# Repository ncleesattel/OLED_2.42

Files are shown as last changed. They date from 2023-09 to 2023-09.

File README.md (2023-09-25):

## OLED 242 pcb
This is an alternative pcb to the one provided by DIYmore.
A key difference is that no smd soldering is necessary to switch from SPI mode to I2C mode.
Instead there is a switch pad that can be used.

I use this pcb to connect 2.42 inch displays from Aliexpress to either my SHC build or the ESP32 dew heater.
Look for 2.42" 128x64 SSD1309 displays and the assoc. metal frame.

## ordering
The pcb is designed in KiCad.  
In the jlcpcb folder you can find the Gerber, BOM and CPL file you need to not only order the pcb, but also the assembled smd parts.

## cost estimate
| Item | Number | Cost |
|---|---|---|
| pcb | 5 | 60 |
| frame | 5 | 13 |
| display | 5 | 52 |

Best case you can use all displays equals to 25/unit.  
Worst case you just need one and can't share the cost of the other four equals to 125. 

## pictures

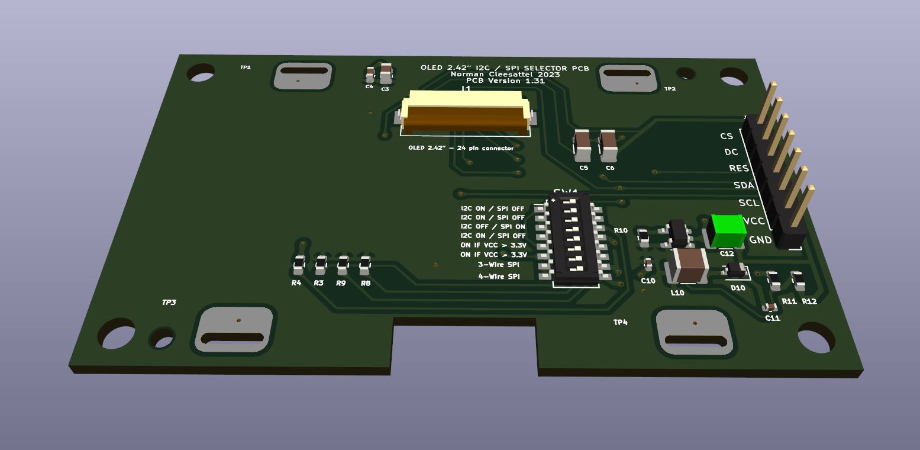
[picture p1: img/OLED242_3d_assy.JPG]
OLED 242 3d pcb


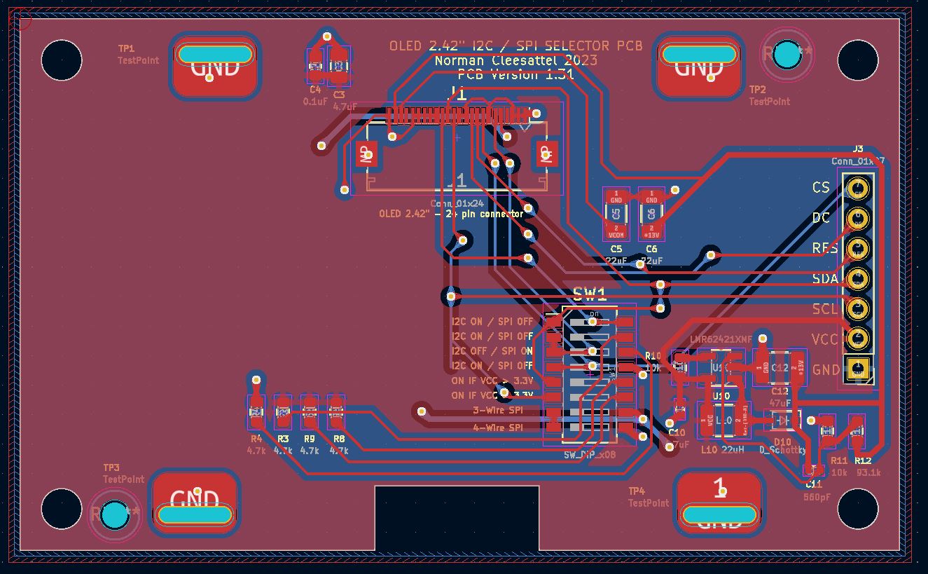
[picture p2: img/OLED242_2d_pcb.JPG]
OLED 242 2d pcb


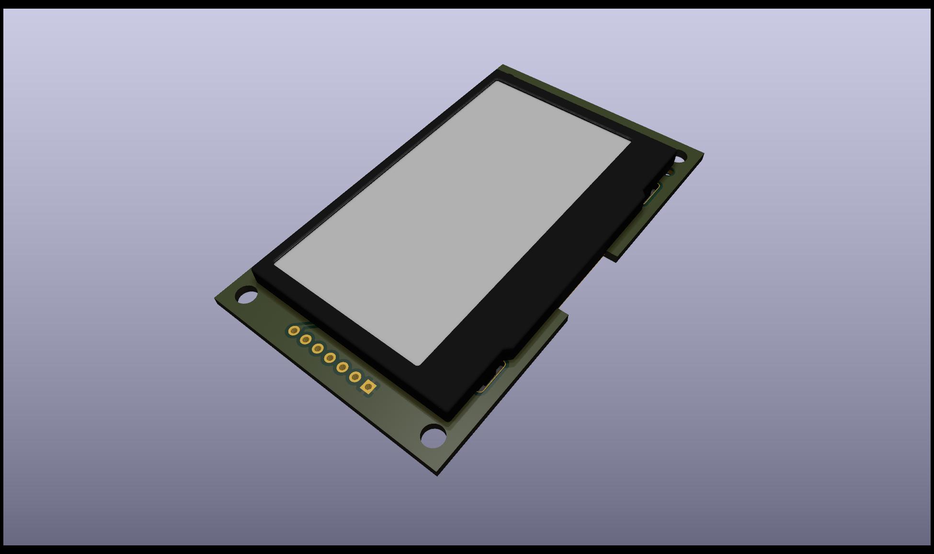
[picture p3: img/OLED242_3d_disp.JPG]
OLED 242 3d disp


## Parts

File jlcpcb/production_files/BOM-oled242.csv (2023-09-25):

Comment | Designator | Footprint | LCSC
22uF | C5,C6 | C_1206_3216Metric | C12891
0.1uF | C4 | C_0603_1608Metric | C14663
4.7uF | C3 | C_0805_2012Metric | C1779
D_Schottky | D10 | D_SOD-323 | C191023
Conn_01x24 | J1 | Hirose_FH12-24S-0.5SH_1x24-1MP_P0.50mm_Horizontal | C202112
LMR62421XMF | U10 | SOT-23-5 | C206031
22uH | L10 | C_1210_3225Metric | C223225
SW_DIP_x08 | SW1 | SW_DIP_SPSTx08_Slide_Omron_A6H-8101_W6.15mm_P1.27mm | C224998
4.7k | R3,R4,R8,R9 | R_0603_1608Metric | C23162
4.7uF | C10 | C_0402_1005Metric | C23733
10k | R10,R11 | R_0603_1608Metric | C25804
560pF | C11 | C_0402_1005Metric | C464953
93.1k | R12 | R_0603_1608Metric | C705799
47uF | C12 | C_1210_3225Metric | C77101
TestPoint | TP2 | OLED_slot
OLED_slot | TP4 | OLED_slot
Conn_01x07 | J3 | PinHeader_1x07_P2.54mm_Vertical
TestPoint | TP3 | OLED_slot
TestPoint | TP1 | OLED_slot

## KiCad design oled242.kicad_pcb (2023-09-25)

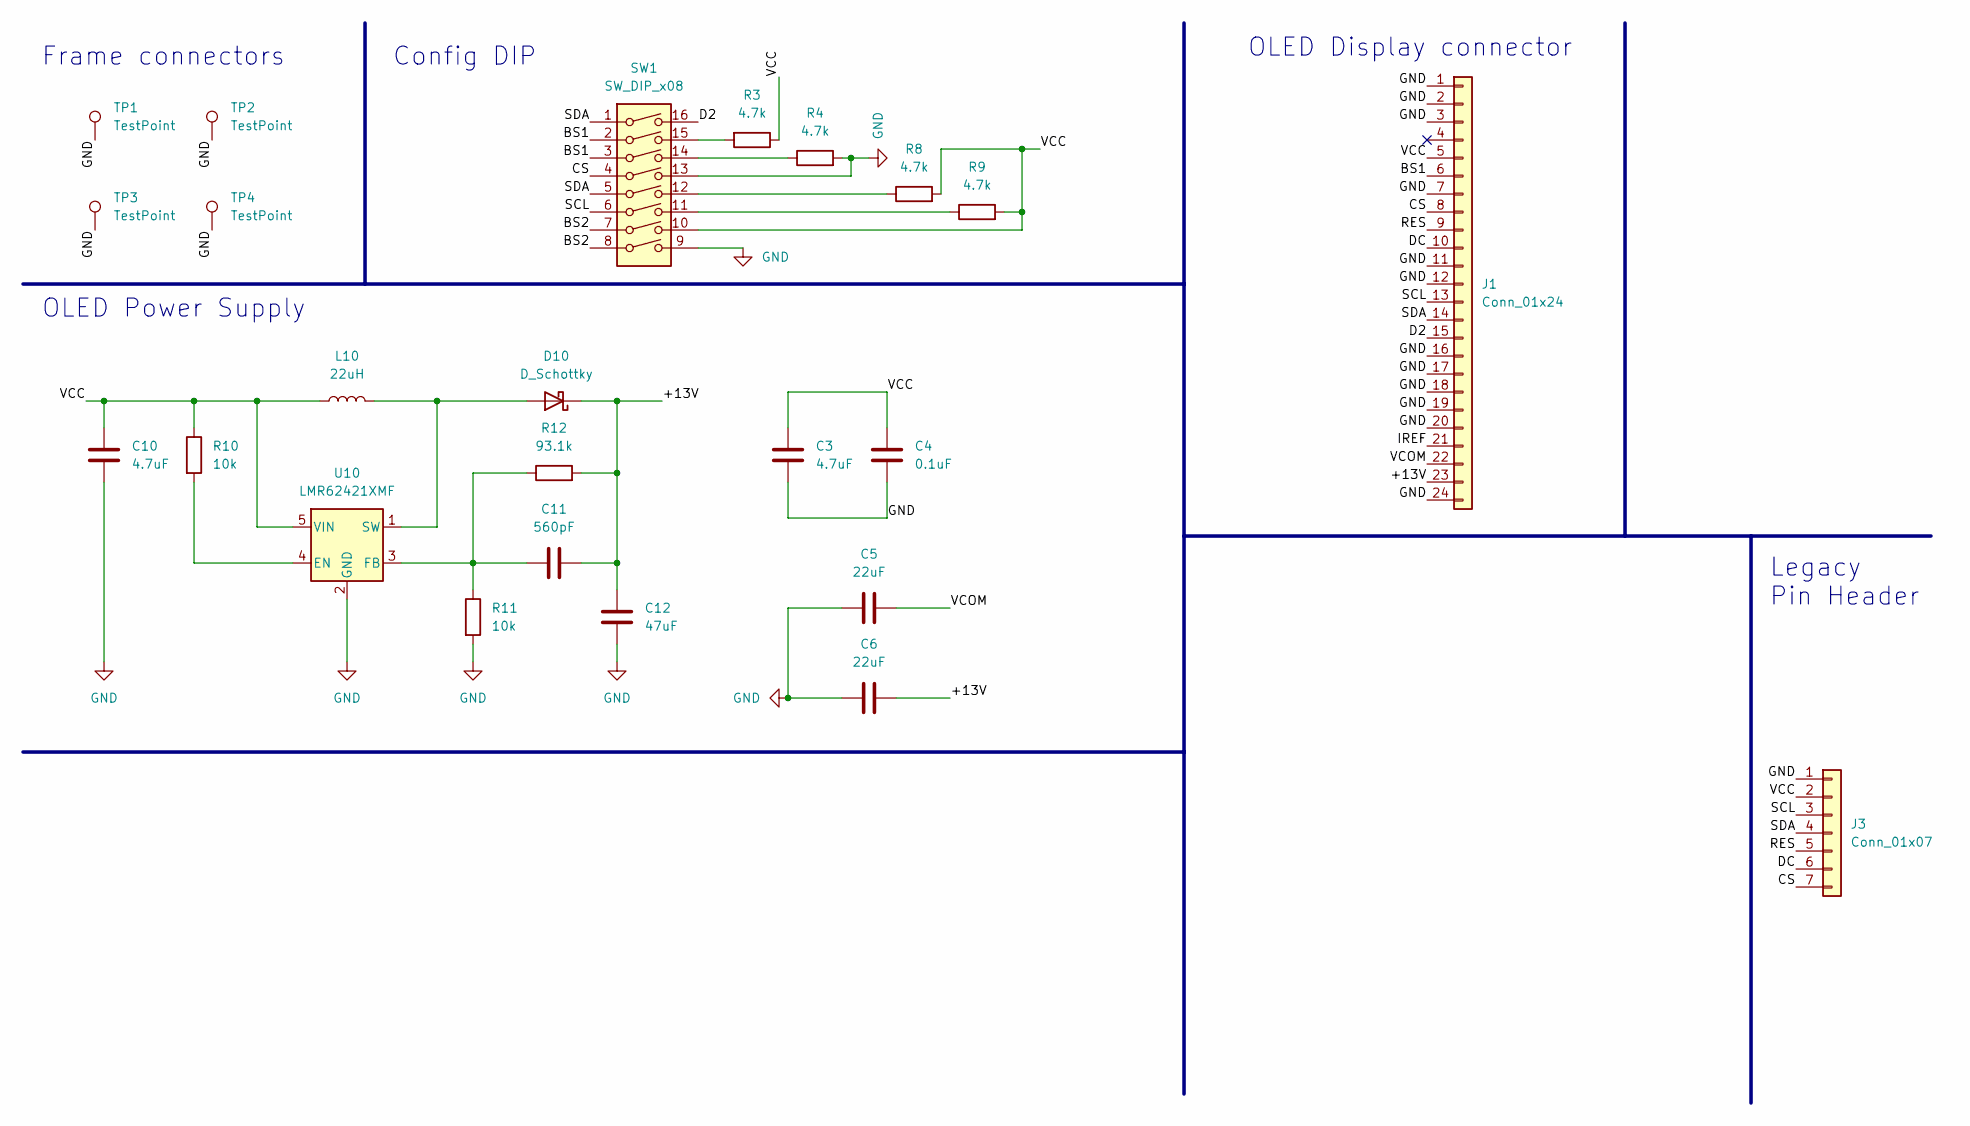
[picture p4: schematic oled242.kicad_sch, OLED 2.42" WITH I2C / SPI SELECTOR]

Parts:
C3: 4.7uF; C_0805_2012Metric; LCSC C1779
C4: 0.1uF; C_0603_1608Metric; LCSC C14663
C5, C6: 22uF; C_1206_3216Metric; LCSC C12891
C10: 4.7uF; C_0402_1005Metric; LCSC C23733
C11: 560pF; C_0402_1005Metric; LCSC C464953
C12: 47uF; C_1210_3225Metric; LCSC C77101
D10: D_Schottky; D_SOD-323; LCSC C191023
J1: Conn_01x24; Hirose_FH12-24S-0.5SH_1x24-1MP_P0.50mm_Horizontal; LCSC C506794
J3: Conn_01x07; PinHeader_1x07_P2.54mm_Vertical
L10: 22uH; C_1210_3225Metric; LCSC C223225
R3, R4, R8, R9: 4.7k; R_0603_1608Metric; LCSC C23162
R10, R11: 10k; R_0603_1608Metric; LCSC C25804
R12: 93.1k; R_0603_1608Metric; LCSC C705799
SW1: SW_DIP_x08; SW_DIP_SPSTx08_Slide_Omron_A6H-8101_W6.15mm_P1.27mm; LCSC C224998
TP1, TP2, TP3, TP4: TestPoint; OLED_slot
U10: LMR62421XMF; SOT-23-5; LCSC C206031

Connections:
/+13V: C6.2, C11.2, C12.2, D10.1 (K), J1.23, R12.2
/BS1: J1.6, SW1.2, SW1.3
/BS2: SW1.7, SW1.8
/CS: J1.8, J3.7, SW1.4
/D2: J1.15, SW1.16
/DC: J1.10, J3.6
/IREF: J1.21
/RES: J1.9, J3.5
/SCL: J1.13, J3.3, SW1.6
/SDA: J1.14, J3.4, SW1.1, SW1.5
/VCC: C3.1, C4.1, C10.1, J1.5, J3.2, L10.1, R3.1, R8.2, R9.2, R10.1, SW1.10, U10.5 (VIN)
/VCOM: C5.2, J1.22
GND: C3.2, C4.2, C5.1, C6.1, C10.2, C12.1, J1.1, J1.2, J1.3, J1.7, J1.11, J1.12, J1.16, J1.17, J1.18, J1.19, J1.20, J1.24, J3.1, R4.2, R11.2, SW1.9, SW1.13, TP1.1, TP2.1, TP3.1, TP4.1, U10.2 (GND)
unnamed: D10.2 (A), L10.2, U10.1 (SW)
unnamed: R3.2, SW1.15
unnamed: R4.1, SW1.14
unnamed: R8.1, SW1.12
unnamed: R9.1, SW1.11
unnamed: R10.2, U10.4 (EN)
unnamed: C11.1, R11.1, R12.1, U10.3 (FB)

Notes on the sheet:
Frame connectors
Legacy Pin Header
OLED Display connector
OLED Power Supply
Config DIP

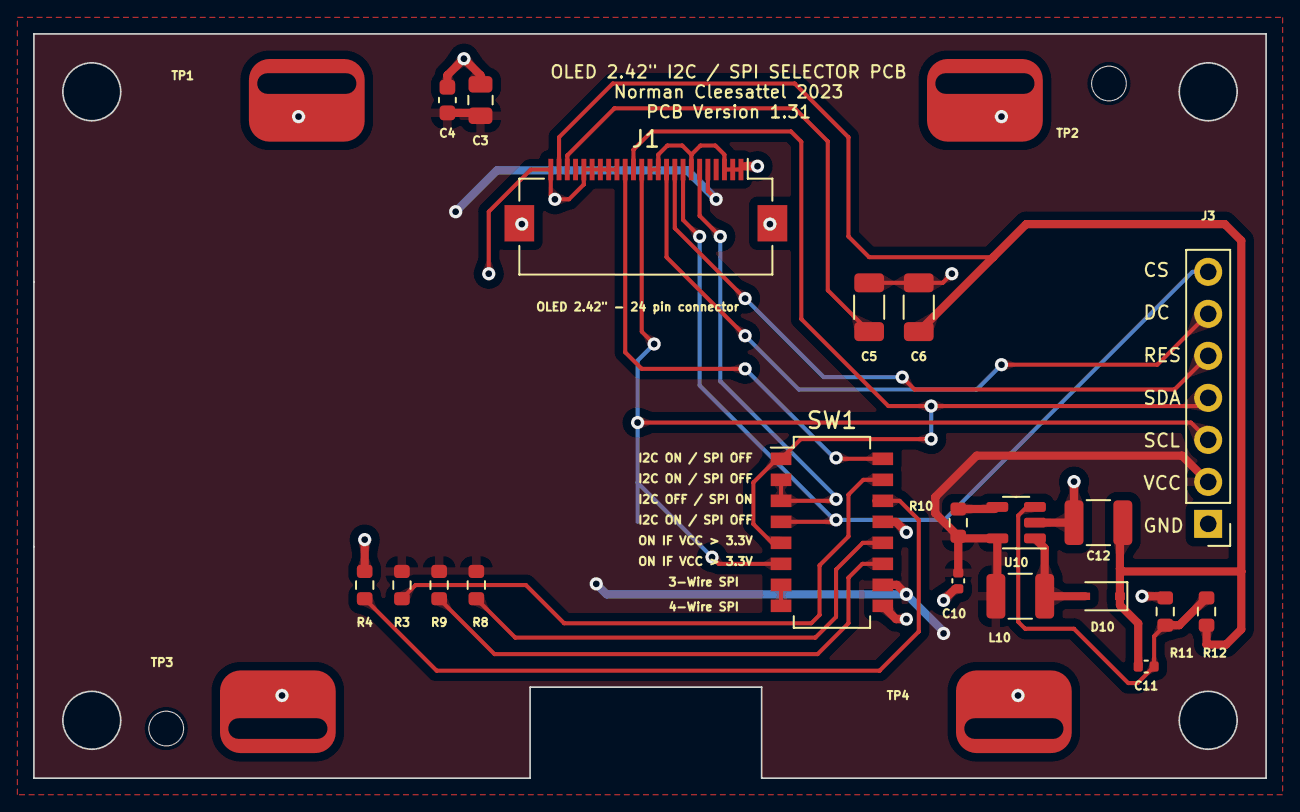
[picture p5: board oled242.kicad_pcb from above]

Board: 2 copper layers, 74.5 x 45.0 mm, 24 parts (0 on the bottom side), 19 nets.
